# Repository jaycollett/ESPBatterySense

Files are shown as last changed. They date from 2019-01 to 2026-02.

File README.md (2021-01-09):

# ESPBatterySense


This project was inspired by my desire to track the humidity, and to a much lesser degree, the temperature inside the storage solution for my 3D printing filament. To goal was to have a device that is battery operated, lasts several months (if not longer) before needing to recharge or replace batteries, and capable of transmitting to my MQTT broker for display and graphing in HASS.IO. I've been working a lot with ESP-based projects and love the the simplicity of the ESP. In this project, which is a varition of the the original that made use of a BME280 sensor, I've moved to a SI7021-A20 IC that is not a seprate daughter-board which I like better. The SI7021-A20 is a great solution for me as it's easily and affordably sourced, well documented, easy to reflow solder in my homemade solution, and has great accuracy.

The firmware is designed to put the ESP in deep sleep for 1 hour and upon reset, take a sample of humidity, temperature, voltage of battery, and then transmit that to my MQTT broker (which happens to be part of my HASS.IO setup). I originally had been using a LiPo battery from Adafruit, and while it worked, it was providing > 3.6V to the board directly. I never saw any negative issues with such a high voltage from the BME280 sensor or the ESP, but it's not a good design practice and it did cause the ESP to consume far more power in deep sleep than voltages closer to 3.3V. For these reasons, I've switched to (2) AA alkaline batteries and have had great longevity thus far with them. Running the prototype design for well over 3 weeks with a tenth of a volt drop on the batteries.

Unfortunately, this design requires a reflow solution as the SI7021 is not something I would classify as easily hand soldered. 

**BOM**
----------
1. [ESP-12S](https://www.aliexpress.com/item/ESP8266-ESP-12E-serial-WIFI-wireless-module-wireless-transceiver-Complete-circuit-impedance-matching-better-signal/32324777806.html)
2. [SI7021-A20](https://www.aliexpress.com/item/100-brand-new-original-Si7021-A20-GM1R-Si7021-A20/32834030103.html) (with protective cover and A20 version not A10)
3. 10K OHM 0805 Resistor (QTY: 5)
4. 0.1UF Ceramic Capacitor X7R 16V 0805 (QTY: 1)
6. [Custom PCB](https://oshpark.com/shared_projects/1hOMQGI8) from OSHPark.com
7. [JST connector](https://www.digikey.com/product-detail/en/jst-sales-america-inc/S2B-PH-K-S%28LF%29%28SN%29/455-1719-ND/926626) for battery
7. Battery (any ~3.3V battery source, I'm using 2 alkaline AA batteries)
8. Optional header for programming and debug pins
9. Enclosure of some sort (my very basic design is [here](https://www.thingiverse.com/thing:3371715)
#



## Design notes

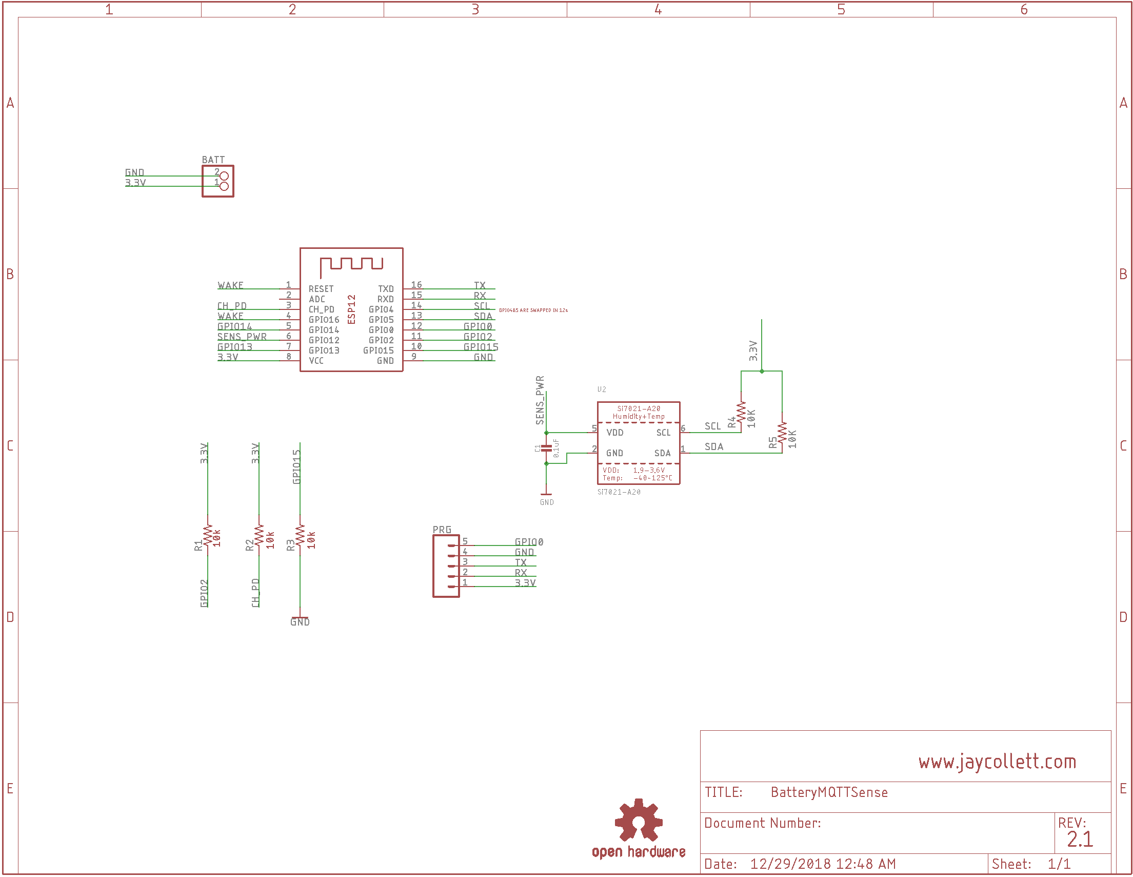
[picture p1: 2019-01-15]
EagleCAD/Schematic.png

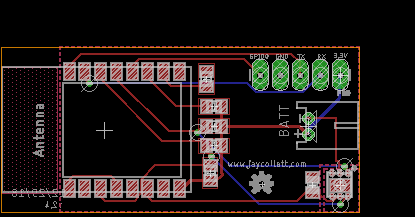
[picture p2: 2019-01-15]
EagleCAD/Board.png

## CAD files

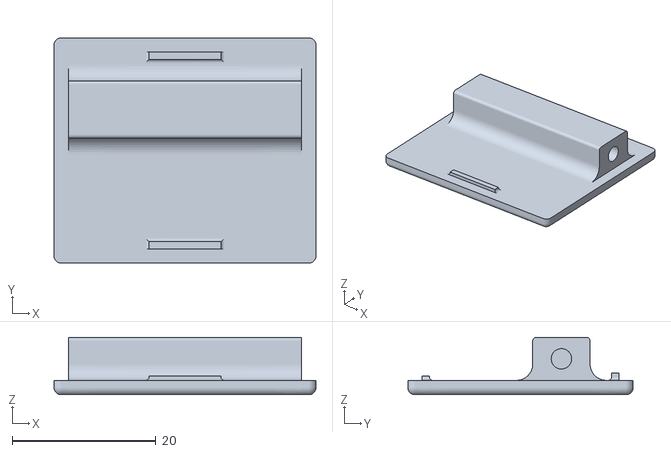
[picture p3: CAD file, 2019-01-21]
Project Enclosure/LID.stl
36.5 x 31.4 x 8.00

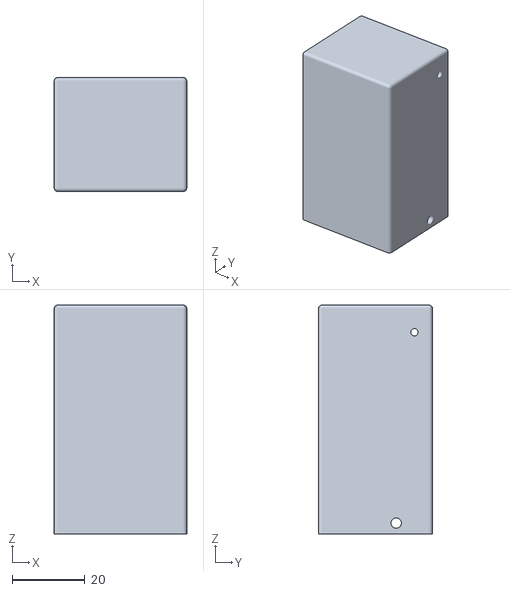
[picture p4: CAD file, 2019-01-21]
Project Enclosure/Case.stl
36.5 x 31.4 x 63.0

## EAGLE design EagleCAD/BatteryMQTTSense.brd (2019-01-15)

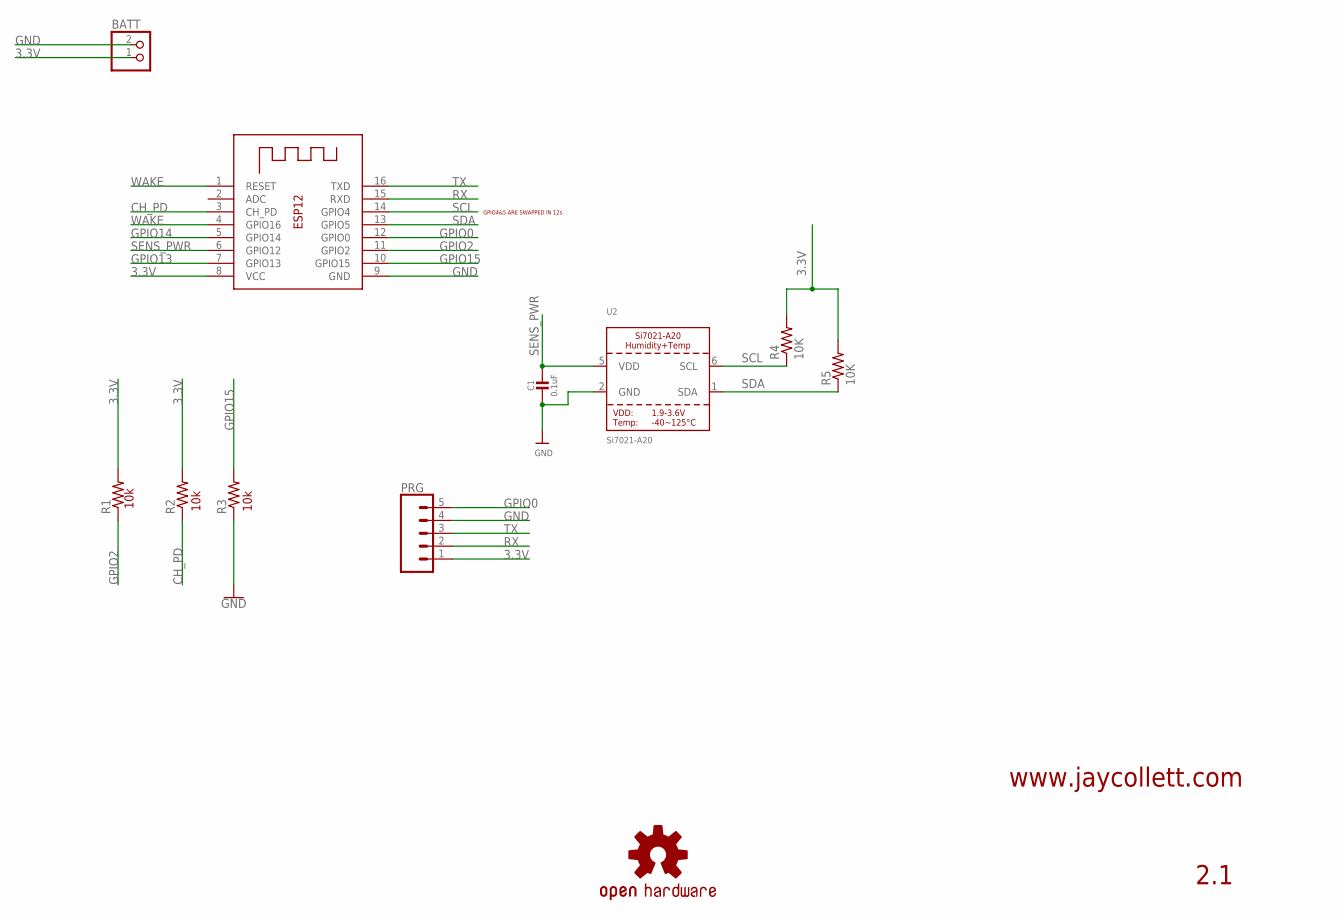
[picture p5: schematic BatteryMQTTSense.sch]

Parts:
BATT: JST_2PIN-THM-RA; JST-PH-2-THM-RA
C1: 0.1uF; 0805-NO
LOGO1: OSHW-LOGOS; OSHW-LOGO-S
PRG: CONN_05PTH_LONGPADS; 1X05_LONGPADS
R1, R2, R3: R-US_M0805; M0805
R4, R5: 10K; M0805
U2: Si7021-A20; DFN6_3X3_SI
_: ESP-12

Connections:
3.3V: BATT.1 (2), PRG.1, R1.2, R2.2, R4.2, R5.2, _.8 (VCC)
CH_PD: R2.1, _.3 (CH_PD)
GND: BATT.2 (1), C1.2, PRG.4, R3.1, U2.2 (GND), _.9 (GND)
GPIO0: PRG.5, _.12 (GPIO0)
GPIO2: R1.1, _.11 (GPIO2)
GPIO13: _.7 (GPIO13)
GPIO14: _.5 (GPIO14)
GPIO15: R3.2, _.10 (GPIO15)
RX: PRG.2, _.15 (RXD)
SCL: R4.1, U2.6 (SCL), _.14 (GPIO4)
SDA: R5.1, U2.1 (SDA), _.13 (GPIO5)
SENS_PWR: C1.1, U2.5 (VDD), _.6 (GPIO12)
TX: PRG.3, _.16 (TXD)
WAKE: _.1 (RESET), _.4 (GPIO16)

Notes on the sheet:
www.jaycollett.com
10k
GPIO4&5 ARE SWAPPED IN 12s
2.1

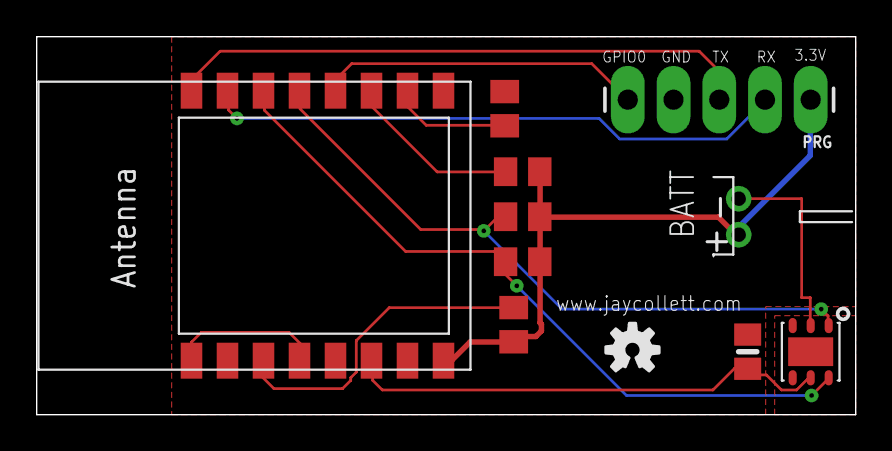
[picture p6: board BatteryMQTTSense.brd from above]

Board: 2 copper layers, 45.5 x 21.0 mm, 11 parts (0 on the bottom side), 12 nets.

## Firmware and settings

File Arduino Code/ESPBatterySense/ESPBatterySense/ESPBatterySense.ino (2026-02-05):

/*
 * ESPBatterySense - Battery-powered temperature/humidity sensor
 * Firmware Version: 3.4
 *
 * Publishes sensor data via MQTT, then deep sleeps to conserve battery.
 * Uses Si7021 sensor and stores WiFi BSSID/channel in RTC memory for fast reconnect.
 */

#include <ESP8266WiFi.h>
#include <PubSubClient.h>
#include "Adafruit_Si7021.h"

// ============================================================================
// USER CONFIGURATION - Change these values for your setup
// ============================================================================

// WiFi credentials
#define WIFI_SSID          "xxxxxxxx"       // Your WiFi network name
#define WIFI_PASS          "xxxxxxxxxx"     // Your WiFi password

// MQTT broker settings
#define MQTT_SERVER        "192.168.0.x"           // MQTT broker IP address
#define MQTT_PORT          1883                    // MQTT broker port (default: 1883)
#define MQTT_USERNAME      "xxxxxxxxxx"            // MQTT username
#define MQTT_PASSWORD      "xxxxxxxxxxxx"          // MQTT password

// Timing settings
#define SLEEP_TIME_SECONDS 3600                   // Deep sleep duration (3600 = 1 hour)

// Hardware settings
#define SENSOR_POWER_PIN   12                     // GPIO pin that powers the sensor

// Debug mode - uncomment to enable serial debug output at 115200 baud
//#define DEBUG

// ===================================================================================
// END OF USER CONFIGURATION - Do not modify below unless you know what you are doing
// ===================================================================================

char fmversion[7] = "3.4";

// Debug macros
#ifdef DEBUG
  #define debug(x)     Serial.print(x)
  #define debugln(x)   Serial.println(x)
#else
  #define debug(x)
  #define debugln(x)
#endif

// RTC memory structure to store WiFi connection info across deep sleep
// This allows skipping WiFi scanning on wake, saving 2-4 seconds
struct {
  uint32_t crc32;       // Checksum to validate data integrity
  uint8_t channel;      // WiFi channel
  uint8_t bssid[6];     // Access point MAC address
  uint8_t padding;      // Align to 4 bytes
} rtcData;

// Sensor reading configuration
const int SENSOR_READ_COUNT = 3;        // Number of readings to average
const int SENSOR_READ_DELAY_MS = 50;    // Delay between readings (ms)
const float TEMP_MIN_C = -40.0;         // Si7021 min temp
const float TEMP_MAX_C = 125.0;         // Si7021 max temp
const float HUMIDITY_MIN = 0.0;
const float HUMIDITY_MAX = 100.0;

const unsigned int connectionAttempts = 10;   // Max WiFi connection attempts

// MQTT topics (generated dynamically from chip ID)
String baseTopic;
String tempTopic;
String humiTopic;
String vccTopic;
String fwTopic;
char mqtt_clientid[30];

// Sensor data buffers
char temperature[10];
char humidity[10];
char vcc[10];
bool sensorReadValid = false;

// Objects
WiFiClient wifiClient;
PubSubClient mqttclient(wifiClient);
Adafruit_Si7021 sensor = Adafruit_Si7021();

ADC_MODE(ADC_VCC);

// Calculate CRC32 for RTC data validation
uint32_t calculateCRC32(const uint8_t *data, size_t length) {
  uint32_t crc = 0xffffffff;
  while (length--) {
    uint8_t c = *data++;
    for (uint32_t i = 0x80; i > 0; i >>= 1) {
      bool bit = crc & 0x80000000;
      if (c & i) {
        bit = !bit;
      }
      crc <<= 1;
      if (bit) {
        crc ^= 0x04c11db7;
      }
    }
  }
  return crc;
}

void setup() {
  // Configure sensor power pin but keep sensor OFF during WiFi activity
  pinMode(SENSOR_POWER_PIN, OUTPUT);
  digitalWrite(SENSOR_POWER_PIN, LOW);

  #ifdef DEBUG
    Serial.begin(115200);
  #endif

  debugln("Waking up to send data to MQTT server...");

  // Generate the unique baseTopic using the chip ID
  String chipID = String(ESP.getChipId(), HEX);
  chipID.toUpperCase();
  baseTopic = "bmesensors/sensor-" + chipID;

  // Recompute the derived MQTT topics
  tempTopic = baseTopic + "/temperature";
  humiTopic = baseTopic + "/humidity";
  vccTopic  = baseTopic + "/vcc";
  fwTopic   = baseTopic + "/firmwarever";

  // Update the MQTT client ID
  snprintf(mqtt_clientid, sizeof(mqtt_clientid), "sensor-%s", chipID.c_str());

  // Log the dynamic topics for debugging
  debugln("Base Topic: " + baseTopic);
  debugln("Temperature Topic: " + tempTopic);
  debugln("Humidity Topic: " + humiTopic);
  debugln("VCC Topic: " + vccTopic);
  debugln("Firmware Topic: " + fwTopic);

  // Set up WiFi and MQTT client
  WiFi.hostname(baseTopic);
  WiFi.mode(WIFI_STA);
  WiFi.persistent(false);
  mqttclient.setServer(MQTT_SERVER, MQTT_PORT);
}

void loop() {
  // ===== PHASE 1: WiFi Connection =====
  // Keep sensor OFF during WiFi to avoid EMI interference and reduce current draw
  WiFi.forceSleepWake();
  delay(1);

  // Try to read WiFi config from RTC memory for fast reconnect
  bool rtcValid = false;
  if (ESP.rtcUserMemoryRead(0, (uint32_t*)&rtcData, sizeof(rtcData))) {
    uint32_t crc = calculateCRC32((uint8_t*)&rtcData.channel, sizeof(rtcData) - sizeof(rtcData.crc32));
    if (crc == rtcData.crc32) {
      rtcValid = true;
      debugln("RTC data valid, attempting fast connect...");
    }
  }

  // Attempt connection - use stored BSSID/channel if available
  if (rtcValid) {
    // Fast connect using stored channel and BSSID (skips scanning)
    WiFi.begin(WIFI_SSID, WIFI_PASS, rtcData.channel, rtcData.bssid, true);
  } else {
    // Normal connect with scanning
    debugln("No valid RTC data, performing full WiFi scan...");
    WiFi.begin(WIFI_SSID, WIFI_PASS);
  }

  unsigned int wifiTry = 0;
  while ((WiFi.status() != WL_CONNECTED) && (wifiTry < connectionAttempts)) {
    delay(500); // Check every 500ms for faster response
    wifiTry++;

    // If fast connect fails after a few tries, fall back to full scan
    if (rtcValid && wifiTry == 4 && WiFi.status() != WL_CONNECTED) {
      debugln("Fast connect failed, falling back to full scan...");
      WiFi.disconnect();
      delay(10);
      WiFi.begin(WIFI_SSID, WIFI_PASS);
      rtcValid = false; // Mark as invalid so we save new data
    }

    debug("WiFi not connected (try ");
    debug(wifiTry);
    debugln(")...");
  }

  // If WiFi connection failed, go to deep sleep
  if (WiFi.status() != WL_CONNECTED) {
    debugln("Going to sleep now, we couldn't connect to WiFi!");
    goToSleep();
  }

  debugln("WiFi connected");
  debug("IP address: ");
  debugln(WiFi.localIP());

  // Save WiFi connection info to RTC memory for next wake
  rtcData.channel = WiFi.channel();
  memcpy(rtcData.bssid, WiFi.BSSID(), 6);
  rtcData.crc32 = calculateCRC32((uint8_t*)&rtcData.channel, sizeof(rtcData) - sizeof(rtcData.crc32));
  ESP.rtcUserMemoryWrite(0, (uint32_t*)&rtcData, sizeof(rtcData));
  debugln("WiFi config saved to RTC memory");

  // ===== PHASE 2: Sensor Reading =====
  // Now that WiFi is connected and stable, power on and read the sensor
  debugln("Powering on sensor...");
  digitalWrite(SENSOR_POWER_PIN, HIGH);
  delay(100); // Allow sensor to power up

  // Initialize sensor
  debugln("Initializing sensor...");
  int sensorRetry = 0;
  while (!sensor.begin() && sensorRetry < 3) {
    debugln("Sensor not detected. Retrying...");
    delay(100);
    sensorRetry++;
  }

  if (sensorRetry >= 3) {
    debugln("Sensor initialization failed after 3 attempts.");
    sensorReadValid = false;
  } else {
    delay(250); // Allow sensor to settle before readings
    debugln("Reading sensor data...");
    sensorRead();
  }

  // Power off sensor immediately after reading
  digitalWrite(SENSOR_POWER_PIN, LOW);
  debugln("Sensor powered off");

  // ===== PHASE 3: VCC Reading =====
  // Read VCC after WiFi connected and sensor off for stable reading
  debugln("Reading VCC from ESP...");
  vccRead();

  // ===== PHASE 4: MQTT Publish =====
  debugln("Calling MQTT Connect");
  MQTT_connect();
  debugln("Pushing data to MQTT server");

  // Build MQTT payload - use null for invalid sensor readings
  char mqttPayload[256];
  if (sensorReadValid) {
    snprintf(mqttPayload, sizeof(mqttPayload),
            "{\"temperature\": \"%s\", \"humidity\": \"%s\", \"vcc\": \"%s\", \"firmware\": \"%s\"}",
            temperature, humidity, vcc, fmversion);
  } else {
    snprintf(mqttPayload, sizeof(mqttPayload),
            "{\"temperature\": null, \"humidity\": null, \"vcc\": \"%s\", \"firmware\": \"%s\"}",
            vcc, fmversion);
  }

  debug("Publishing JSON Payload: ");
  debugln(mqttPayload);

  // Publish with retain flag so HA keeps last value across restarts
  int mqttRetValue = mqttclient.publish(baseTopic.c_str(), mqttPayload, true);
  debug("Publish return value: ");
  debugln(mqttRetValue);

  // Retry once if publish failed
  if (mqttRetValue != 1) {
    debugln("MQTT publish failed, retrying...");
    delay(100);
    mqttclient.loop();
    mqttRetValue = mqttclient.publish(baseTopic.c_str(), mqttPayload, true);
    debug("Retry publish return value: ");
    debugln(mqttRetValue);
  }

  // ===== PHASE 5: Clean Shutdown =====
  // Ensure MQTT message is sent before disconnecting
  mqttclient.loop();
  yield();
  delay(100);
  mqttclient.disconnect();
  wifiClient.flush();
  wifiClient.stop();

  debugln("Going to sleep now!");
  goToSleep();
}

void MQTT_connect() {
  if (mqttclient.connected()) {
    return;
  }

  debugln("Connecting to MQTT broker...");
  int retryCount = 0;

  while (!mqttclient.connected() && retryCount < 10) {
    if (mqttclient.connect(mqtt_clientid, MQTT_USERNAME, MQTT_PASSWORD)) {
      debugln("MQTT connected.");
    } else {
      retryCount++;
      debug("Failed to connect, state: ");
      debugln(mqttclient.state());
      delay(1000);
    }
  }

  if (!mqttclient.connected()) {
    debugln("MQTT connection failed. Entering deep sleep.");
    goToSleep();
  }
}

void vccRead() {
  float v = ESP.getVcc() / 1000.0; // Convert to volts
  snprintf(vcc, sizeof(vcc), "%.2f", v); // Format voltage as string
}

void goToSleep() {
  // Ensure sensor is powered off
  digitalWrite(SENSOR_POWER_PIN, LOW);

  // Properly shut down WiFi to minimize power draw
  WiFi.disconnect(true);
  WiFi.mode(WIFI_OFF);
  WiFi.forceSleepBegin();
  delay(1); // Required for modem sleep to take effect

  debugln("Entering deep sleep...");
  ESP.deepSleep(SLEEP_TIME_SECONDS * 1000000UL);

  // Should never reach here, but just in case
  while (true) {
    delay(50);
  }
}

void sensorRead() {
  float tempSum = 0;
  float humiditySum = 0;
  int validReadings = 0;

  // Take multiple readings and average them for accuracy
  for (int i = 0; i < SENSOR_READ_COUNT; i++) {
    float t = sensor.readTemperature();
    float h = sensor.readHumidity();

    // Validate reading is not NaN and within sensor specs
    if (!isnan(t) && !isnan(h) &&
        t >= TEMP_MIN_C && t <= TEMP_MAX_C &&
        h >= HUMIDITY_MIN && h <= HUMIDITY_MAX) {
      tempSum += t;
      humiditySum += h;
      validReadings++;
      debug("Reading ");
      debug(i + 1);
      debug(": T=");
      debug(t);
      debug("C, H=");
      debug(h);
      debugln("%");
    } else {
      debug("Reading ");
      debug(i + 1);
      debugln(": Invalid or out of range");
    }

    if (i < SENSOR_READ_COUNT - 1) {
      delay(SENSOR_READ_DELAY_MS);
    }
  }

  // Check if we got enough valid readings
  if (validReadings == 0) {
    debugln("No valid sensor readings obtained.");
    sensorReadValid = false;
    snprintf(temperature, sizeof(temperature), "0.00");
    snprintf(humidity, sizeof(humidity), "0.00");
    return;
  }

  // Calculate averages
  float avgTempC = tempSum / validReadings;
  float avgHumidity = humiditySum / validReadings;

  // Convert to Fahrenheit
  float avgTempF = (avgTempC * 1.8) + 32;

  debug("Averaged ");
  debug(validReadings);
  debug(" readings: T=");
  debug(avgTempF);
  debug("F, H=");
  debug(avgHumidity);
  debugln("%");

  sensorReadValid = true;
  snprintf(temperature, sizeof(temperature), "%.2f", avgTempF);
  snprintf(humidity, sizeof(humidity), "%.2f", avgHumidity);
}

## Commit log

2018-03-21 adding arduino stubs
2018-03-21 arduino sketch stub
2018-03-26 updating Arduino folder structure
2018-03-27 adding code to power the dht on pin 0
2018-03-31 adding eagle files for board v1.0
    [BatteryMQTTSense.brd, BatteryMQTTSense.sch]
2018-04-09 adding new design for eaglecad files, using daughterboard for bme
    [BatteryMQTTSense.brd, BatteryMQTTSense.sch]
2018-04-09 updating schematic and board and added png file versions
    [BatteryMQTTSense.sch]
2018-04-09 updating firmware to fix pin mapping issue
    [ESPBatterySense.ino]
2018-04-26 modifing code to fix issue with deepsleep zombie mode...
    [ESPBatterySense.ino]
2018-04-29 attempting to fix accuracy issues of sensor readings..
    [ESPBatterySense.ino]
2018-12-13 first version of PCB for SI Sensor version
2018-12-23 update arduino code to support SI7021 sensor and clean up delays
2019-01-14 fixing issue with sensor proxmity to mcu and other tweaks
    [BatteryMQTTSense.brd, BatteryMQTTSense.sch]
2019-01-15 Update README.md
    updated link to pcb on oshpark
2019-01-21 pushing validated version of board and firmware, including stl files for enclosure
    [BatteryMQTTSense.brd, BatteryMQTTSense.sch, Case.stl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]
2024-01-20 Updates debug serial out text, tweaks to try to save a bit more power
2024-01-21 Removed debug define, ready for config and burning to 12s chips
    [ESPBatterySense.ino]
2024-10-08 Updates firmware to prevent battery drain on failed Wifi connection.
    [ESPBatterySense.ino]
2025-01-22 Adds logic to dynamically create device CHIPID base topic and includes calculated battery percentage topic
2025-01-22 Adds more refined logic to MQTT to reduce time alive. Adds more error logic
    [ESPBatterySense.ino]
2025-01-22 Removes the capacity, cleans up code.
2025-01-22 Fixes bug with JSON payload having a space before the vcc value. Bumps version number to 3.2
    [ESPBatterySense.ino]
2025-01-23 Adds updated function for sensor reading, consistent with vcc function, other small tweaks.
2026-02-05 Updates firmware for even more battery life savings. Mainly Quick connect to WiFi by caching BSSID, etc. tweaks to sensor timings, etc.

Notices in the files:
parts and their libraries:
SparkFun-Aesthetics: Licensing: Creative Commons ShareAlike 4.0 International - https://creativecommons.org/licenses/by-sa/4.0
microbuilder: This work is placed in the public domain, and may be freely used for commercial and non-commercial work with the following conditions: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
